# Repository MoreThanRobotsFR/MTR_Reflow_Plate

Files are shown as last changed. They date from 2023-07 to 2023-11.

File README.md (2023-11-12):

# MTR Reflow Plate

<p align="center">

&nbsp;

&nbsp;

&nbsp;

</p>

## Description du projet
Le projet MTR Reflow Plate est un contrôleur de température pour une plaque de refusion. Il permet de réguler la température de la plaque et de suivre les différentes zones de température lors du processus de refusion.

<p align="center">
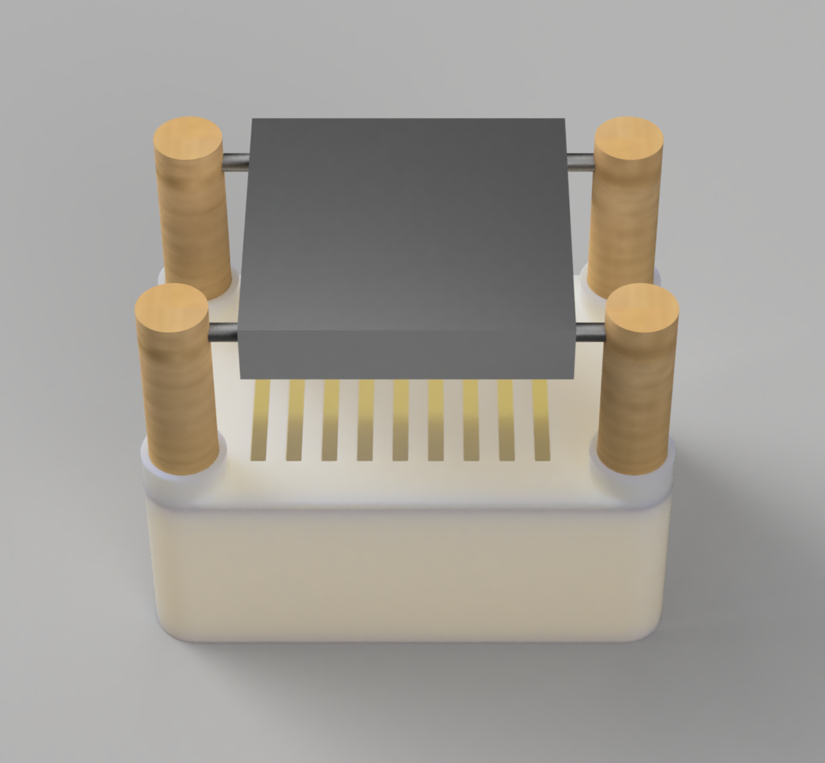
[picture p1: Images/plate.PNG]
MTR Reflow Plate

</p>

## Plateforme matériel
La plateforme matérielle utilisée est l'ESP32 DevKit V1, un microcontrôleur à base de WiFi et Bluetooth intégré. Elle est utilisée en combinaison avec un capteur de température PT100 K avec un MAX31865 et un corps chauffant.

<p align="center">
ESP32, MAX31865 and heating element
</p>

## Installation du firmware
Le code du firmware se trouve dans le répertoire "fireware".

### Prérequis
- La version du logiciel Arduino IDE utilisée doit être compatible avec l'ESP32.
- Les bibliothèques suivantes doivent être installées via le gestionnaire de bibliothèques d'Arduino :
  - Wire
  - SPI
  - SPIFFS
  - [ESPmDNS](https://github.com/espressif/arduino-esp32/tree/master/libraries)
  - [AutoPID](https://github.com/r-downing/AutoPID)
  - [Adafruit_MAX31865](https://github.com/adafruit/Adafruit_MAX31865)
  - [ESPAsyncWebServer](https://github.com/me-no-dev/ESPAsyncWebServer)
  - [AsyncElegantOTA](https://github.com/ayushsharma82/AsyncElegantOTA)
  - [ESPConnect](https://github.com/ayushsharma82/ESPConnect)
  - [ESPAsyncTCP](https://github.com/me-no-dev/ESPAsyncTCP)
  - [Adafruit_BusIO](https://github.com/adafruit/Adafruit_BusIO)
  
  *(`ESPAsyncTCP` et `Adafruit_BusIO` ne sont pas inclus dans le code source du firmware, mais sont nécessaire pour compiler le code. La bibliothèque `ESPmDNS` est incluse dans le package ESP32 pour Arduino IDE)*

### Configuration du matériel
1. Connectez le capteur de température MAX31865 à l'ESP32 comme suit :
   - CS du MAX31865 à la broche `5` 
   - MOSI du MAX31865 à la broche `23` 
   - MISO du MAX31865 à la broche `19` 
   - CLK du MAX31865 à la broche `18` 
2. Connectez le corps chauffant à la broche `4`
3. Connectez le bouton reset à la broche `15` (facultatif)
4. Connectez les leds d'état (facultatif) :
    - LED verte à la broche `12` (dernière etape du processus de refusion)
    - LED rouge à la broche `14` (temperature atteinte)
    - LED bleue à la broche `27` (processus de refusion en cours)
    - LED blanche à la broche `26` (processus de refusion en pause)
    - LED jaune à la broche `32` (mode manuel activé)

### Téléchargement et configuration du firmware
1. Téléchargez le code source du firmware depuis le répertoire "fireware".
2. Ouvrez le fichier "MTR_Reflow_Plate/fireware/src/main.cpp" dans l'IDE Arduino.
3. Modifiez les paramètres de température et de durée des différentes zones selon vos besoins.
4. Compilez et téléchargez le code sur l'ESP32.
4. Si vous souhaitez personnaliser le nom du réseau et le mot de passe WiFi, connectez vous au reseau WiFi "MTR_XXXX" et accédez au portail captif en entrant l'adresse `http://mtr-reflow-plate.local/` dans votre navigateur Web.

### Connexion WiFi avec Portail Captif et Mise à jour OTA

La plaque de refusion MTR utilise la bibliothèque ESPConnect.h pour gérer la connexion WiFi avec portail captif, simplifiant ainsi le processus de configuration du réseau. La bibliothèque AsyncElegantOTA.h permet quant à elle la mise à jour OTA du firmware de la plaque de refusion de manière pratique et sans fil. Ces fonctionnalités offrent une expérience utilisateur améliorée en facilitant la connexion à un réseau WiFi et en permettant la mise à jour du firmware en quelques étapes simples.

## Utilisation de l'interface utilisateur
Lorsque le firmware est correctement chargé sur l'ESP32, vous pouvez accéder à l'interface utilisateur depuis un navigateur Web en entrant l'adresse IP attribuée à l'ESP32.

L'interface utilisateur dispose de plusieurs fonctionnalités :
- **Temperature**: Affiche la valeur actuelle de la température.
- **SET Params**: Permet de définir les paramètres de température et de durée des différentes zones.
- **START**: Démarre le processus de refusion selon les paramètres définis.
- **STOP**: Arrête le processus de refusion.
- **MANU**: Permet de passer en mode de contrôle manuel de la température.
- **Chart**: Affiche un graphique des températures mesurées.

## Exemple de code pour l'utilisation de l'API REST
Il est possible de contrôler la refusion en utilisant l'API REST fournie par l'ESP32.

Voici quelques exemples d'utilisation de l'API REST :
- Récupérer la température actuelle :
  ```
  GET /readTemperature
  ```
- Récupérer la consigne de température actuelle :
  ```
  GET /readSetPoint
  ```
- Définir les paramètres de température et de durée des différentes zones :
  ```
  POST /params
  Content-Type: application/x-www-form-urlencoded
  
  temps_zone_preheating=100000&temperature_zone_preheating=80&temps_zone_recirculation=100000&temperature_zone_recirculation=120&temps_zone_reflow=10000&temperature_zone_reflow=183&temperature_zone_cooling=23
  ```
Pour plus d'informations sur l'utilisation de l'API REST, veuillez consulter le fichier [Firmware/MTR_Reflow_Plate/data/README.md](./Fimrware/MTR_Reflow_Plate/data/README.md).

## Documentation de l'interface web

### Introduction
L'interface web de la plaque de refusion MTR permet de visualiser la température actuelle, de contrôler le mode de fonctionnement (automatique ou manuel) et de configurer les paramètres de refusion. Cette documentation présente les pages principales de l'interface : index.html, manu.html et chart.html.

### index.html
La page index.html est la page d'accueil de l'interface web de la plaque de refusion MTR. Elle permet de visualiser la température actuelle, de configurer les paramètres de refusion et de contrôler le démarrage et l'arrêt du processus de refusion. La page comprend les sections suivantes :

- **Température actuelle** : Affiche la température actuelle de la plaque de refusion en degrés Celsius.
- **Configuration des paramètres** : Permet de définir les temps et les températures de chaque zone de refusion (préchauffage, recirculation, refusion et refroidissement).
- **Boutons de contrôle** : Permettent de démarrer ou d'arrêter le processus de refusion, ainsi que de passer en mode manuel.
- **Affichage des paramètres** : Affiche les paramètres de refusion actuels.

<p align="center">
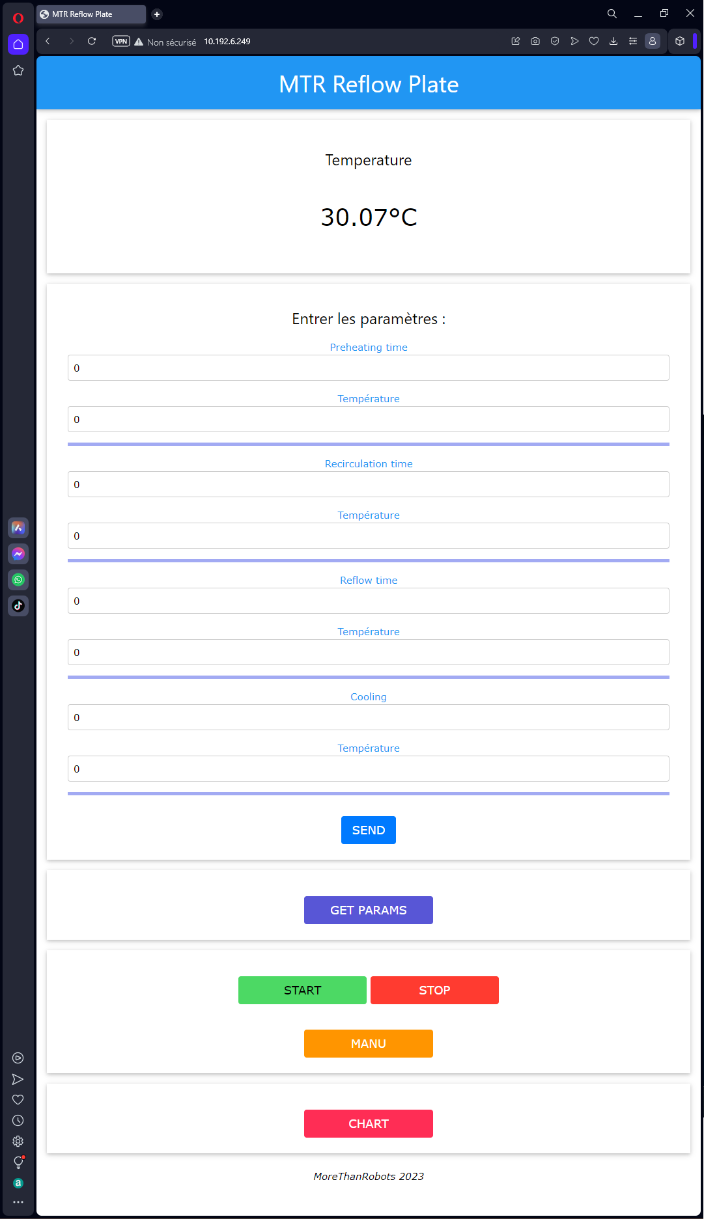
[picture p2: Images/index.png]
index.html

</p>

### manu.html
La page manu.html permet de contrôler la plaque de refusion en mode manuel. Elle affiche la température actuelle et permet de définir une température manuelle. La page comprend les sections suivantes :

- **Température actuelle** : Affiche la température actuelle de la plaque de refusion en degrés Celsius.
- **Définition de la température manuelle** : Permet de définir une température manuelle pour la plaque de refusion.
- **Boutons de contrôle** : Permettent de démarrer ou d'arrêter le chauffage ou le refroidissement de la plaque de refusion.

<p align="center">
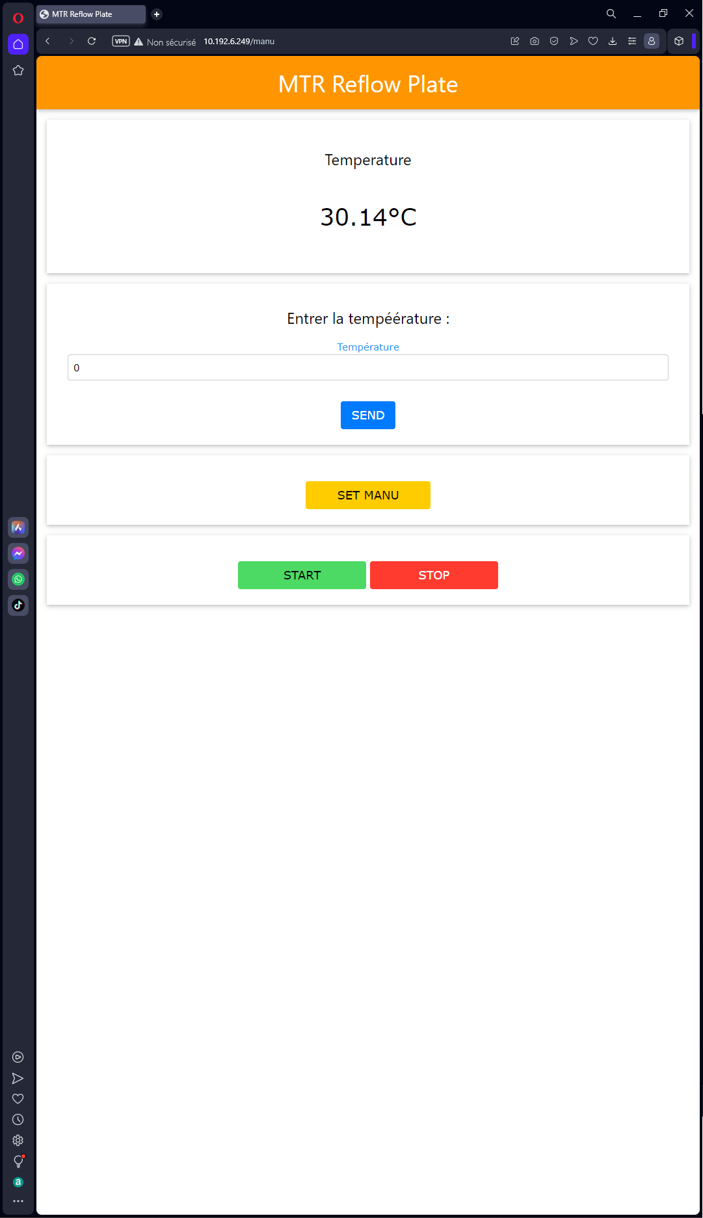
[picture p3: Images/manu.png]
manu.html

</p>

### chart.html
La page chart.html affiche un graphique en temps réel de la température de la plaque de refusion. Le graphique est mis à jour automatiquement toutes les quelques secondes et affiche la température actuelle ainsi que la température de consigne. La page comprend les sections suivantes :

- **Graphique de température** : Affiche le graphique en temps réel de la température de la plaque de refusion et de la température de consigne.

<p align="center">
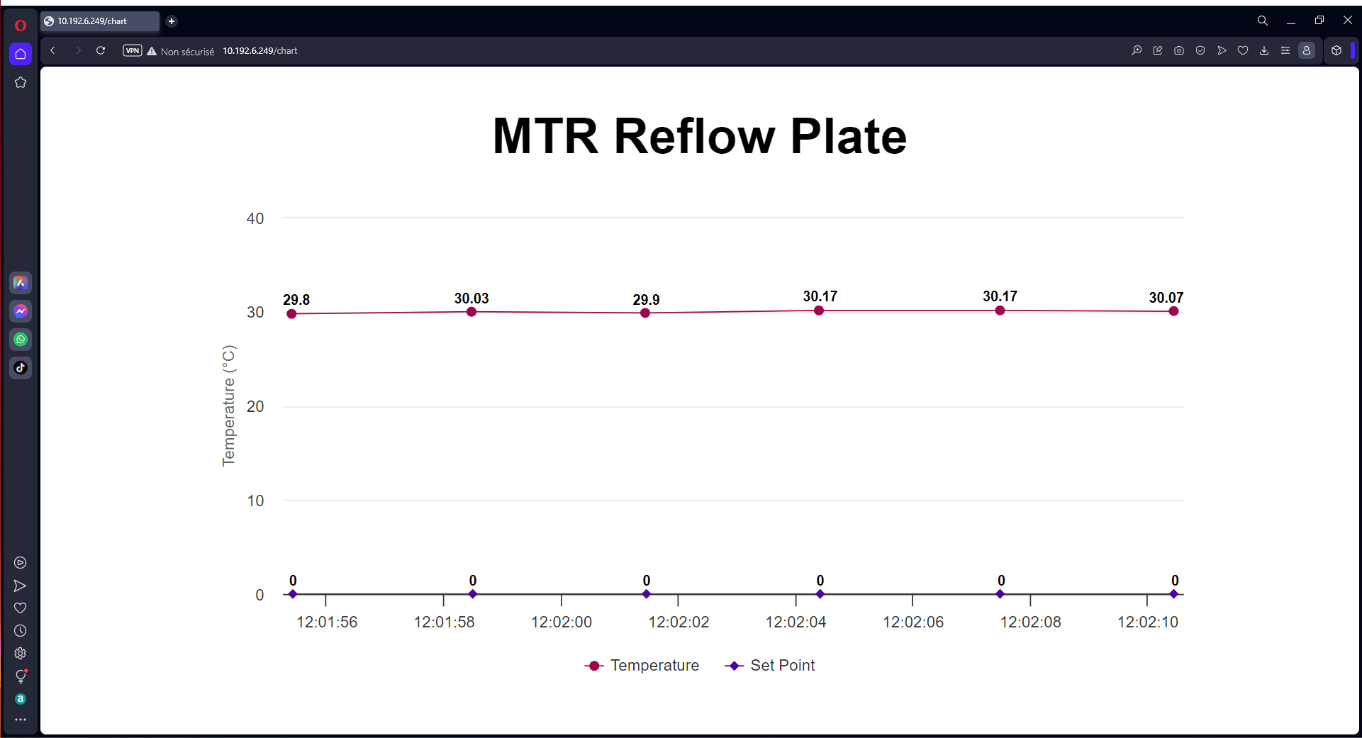
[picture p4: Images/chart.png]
chart.html

</p>

### Conclusion
L'interface web de la plaque de refusion MTR offre une visualisation claire de la température actuelle de la plaque, ainsi que des fonctionnalités de contrôle et de configuration pour le processus de refusion. Les pages index.html, manu.html et chart.html fournissent une interface conviviale pour interagir avec la plaque de refusion et surveiller le processus de refusion en temps réel.

## Auteur
Ce projet a été développé par Ciciliano Altmann pour MTR (MoreThanRobots).

## Licence
Ce projet est distribué sous licence MIT. Veuillez consulter le fichier "LICENSE" pour plus d'informations.

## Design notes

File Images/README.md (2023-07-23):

<p align="center">
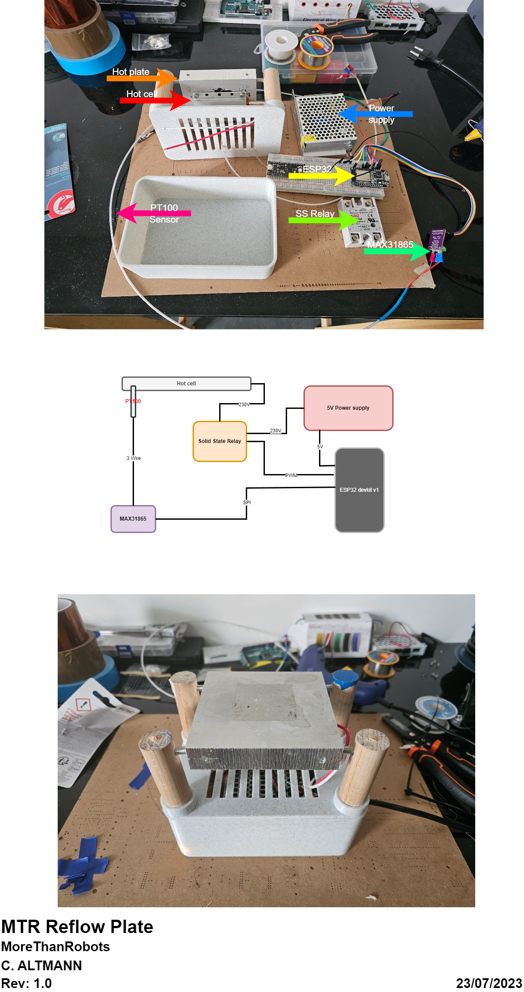
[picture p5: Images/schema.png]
MTR Reflow Plate

</p>

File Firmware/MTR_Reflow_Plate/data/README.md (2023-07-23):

# Documentation de l'API

## Introduction
Cette API vous permet de contrôler la température d'une plaque de refusion. Elle fournit des points de terminaison pour récupérer la température actuelle, définir la température souhaitée, démarrer et arrêter le processus de refusion, et configurer les paramètres de chaque zone de refusion.

## Points de terminaison

### Récupérer la température actuelle
- Méthode : `GET`
- Point de terminaison : `/readTemperature`
- Réponse : La température actuelle en degrés Celsius

### Récupérer la température de consigne
- Méthode : `GET`
- Point de terminaison : `/readSetPoint`
- Réponse : La température de consigne souhaitée en degrés Celsius

### Démarrer le processus de refusion
- Méthode : `GET`
- Point de terminaison : `/start`
- Réponse : Aucune

### Arrêter le processus de refusion
- Méthode : `GET`
- Point de terminaison : `/stop`
- Réponse : Aucune

### Définir le mode manuel
- Méthode : `POST`
- Point de terminaison : `/manu`
- Paramètres de la requête :
  - `manuMode` : le mode souhaité (0 pour automatique, 2 pour manuel)
- Réponse : Aucune

### Définir la température manuelle
- Méthode : `POST`
- Point de terminaison : `/manuSetTemperature`
- Paramètres de la requête :
  - `manuTemperature` : la température souhaitée en degrés Celsius
- Réponse : Aucune

### Définir les paramètres de refusion
- Méthode : `POST`
- Point de terminaison : `/params`
- Paramètres de la requête :
  - `temps_zone_preheating` : la durée de la zone de préchauffage en secondes
  - `temperature_zone_preheating` : la température de la zone de préchauffage en degrés Celsius
  - `temps_zone_recirculation` : la durée de la zone de recirculation en secondes
  - `temperature_zone_recirculation` : la température de la zone de recirculation en degrés Celsius
  - `temps_zone_reflow` : la durée de la zone de refusion en secondes
  - `temperature_zone_reflow` : la température de la zone de refusion en degrés Celsius
  - `temps_zone_cooling` : la durée de la zone de refroidissement en secondes
  - `temperature_zone_cooling` : la température de la zone de refroidissement en degrés Celsius
- Réponse : Aucune

### Récupérer les paramètres de refusion
- Méthode : `GET`
- Point de terminaison : `/getParams`
- Réponse : Les paramètres de refusion actuels sous la forme d'un objet JSON avec les propriétés suivantes :
  - `temps_zone_preheating` : la durée de la zone de préchauffage en secondes
  - `temperature_zone_preheating` : la température de la zone de préchauffage en degrés Celsius
  - `temps_zone_recirculation` : la durée de la zone de recirculation en secondes
  - `temperature_zone_recirculation` : la température de la zone de recirculation en degrés Celsius
  - `temps_zone_reflow` : la durée de la zone de refusion en secondes
  - `temperature_zone_reflow` : la température de la zone de refusion en degrés Celsius
  - `temperature_zone_cooling` : la température de la zone de refroidissement en degrés Celsius

## Explication des modes

### Mode automatique
En mode automatique, le processus de refusion suit un profil de température prédéfini qui comprend quatre zones : préchauffage, recirculation, refusion et refroidissement. La durée et la température de chaque zone peuvent être configurées à l'aide du point de terminaison `/params`.

Pour démarrer le processus de refusion en mode automatique, envoyez une requête GET au point de terminaison `/start`. Le processus de refusion s'exécutera conformément aux paramètres configurés jusqu'à ce qu'il atteigne la zone de refroidissement. À la fin de la zone de refroidissement, le processus s'arrêtera automatiquement.

Pour arrêter le processus de refusion, envoyez une requête GET au point de terminaison `/stop`.

### Mode manuel
En mode manuel, vous pouvez définir une température souhaitée pour la plaque de refusion. La plaque de refusion chauffera ou refroidira jusqu'à atteindre la température souhaitée.

Pour activer le mode manuel, envoyez une requête POST au point de terminaison `/manu` avec le paramètre `manuMode` défini sur 2. Cela activera le mode manuel.

Pour définir la température souhaitée en mode manuel, envoyez une requête POST au point de terminaison `/manuSetTemperature` avec le paramètre `manuTemperature` défini sur la température souhaitée en degrés Celsius.

Pour commencer à chauffer ou à refroidir la plaque de refusion en mode manuel, envoyez une requête GET au point de terminaison `/manuStart`.

Pour arrêter le processus de chauffage ou de refroidissement en mode manuel, envoyez une requête GET au point de terminaison `/manuStop`.

## Gestion des erreurs
En cas d'erreur, le serveur répondra avec un code d'état HTTP approprié et un message d'erreur dans le corps de la réponse.

Codes d'erreur possibles :
- 400 : Requête incorrecte - La requête est invalide ou des paramètres obligatoires sont manquants.
- 404 : Non trouvé - La ressource ou le point de terminaison demandé n'existe pas.
- 500 : Erreur interne du serveur - Une erreur inattendue s'est produite sur le serveur.

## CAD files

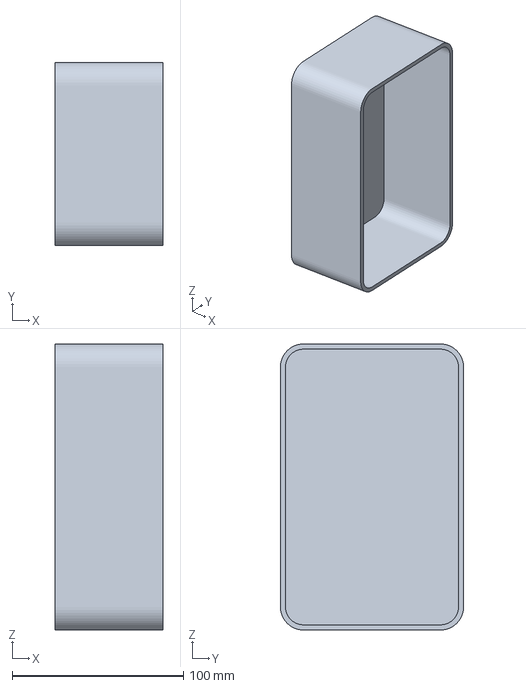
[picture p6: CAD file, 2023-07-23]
Models/support inf v3.3mf
63.0 x 107.0 x 167.0 mm

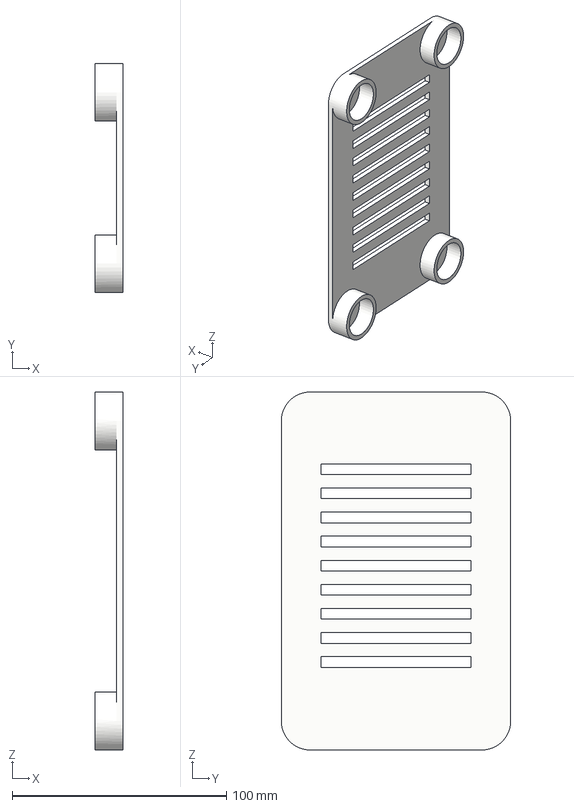
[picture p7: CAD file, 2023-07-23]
Models/support dip v5.3mf
13.0 x 107.0 x 167.0 mm

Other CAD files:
Models/Ass v5.f3z
Models/Cellule chauffante v3.f3d
Models/Pilier v1.f3d
Models/Plateau chauffant v5.f3d
Models/Support disipateur v1.f3d
Models/support dip v5.f3d
Models/support inf v3.f3d

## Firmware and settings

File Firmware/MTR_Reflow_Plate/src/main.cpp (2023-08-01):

/*
Name: MTR Reflow Plate
Version: 1.2.0
Description: This program is used to control the temperature of a reflow plate.
Plateform: ESP32 DevKit V1
Author: Ciciliano Altmann (MTR)
Date: 23/07/2023
License: MIT License
*/

#include <Arduino.h>
#include <Wire.h>
#include <SPI.h>
#include <ESPmDNS.h>
#include <AutoPID.h>
#include <Adafruit_MAX31865.h>
#include <ESPAsyncWebServer.h>
#include <SPIFFS.h>
#include <AsyncElegantOTA.h>
#include <ESPConnect.h>


#define RREF 430.0
#define RNOMINAL 100.0

#define OUTPUT_PIN 4
#define LED_PIN 2
#define LED_GREEN 12
#define LED_RED 14
#define LED_BLUE 27
#define LED_WHITE 26
#define LED_YELLOW 32

#define BUTTON_EREASE 15

#define SPI_CS 5
#define SPI_MOSI 23
#define SPI_MISO 19
#define SPI_CLK 18

#define OUTPUT_MIN 0
#define OUTPUT_MAX 255
#define KP 100
#define KI 0.5
#define KD 0

bool inZone(unsigned long elapsedMilliseconds, unsigned long zoneDuration);
float getTemperature(float R_NOMINAL, float R_REF);
void setTemperature(float temperature);

double temperature, outputVal, setPoint, manuSetPoint;
int startStopManu = 0;
bool manu = false;

// un entier aléatoire en 1000 et 9999

int randNb = random(1001, 9999);
String wifiAPName = "MTR_" + String(randNb);

// Sn42Bi58 paste profile
unsigned long preheatingTime = 60000;     // Durée de la zone 1 (en millisecondes)
unsigned long recirculationTime = 100000; // Durée de la zone 2 (en millisecondes)
unsigned long reflowTime = 90000;         // Durée de la zone 3 (en millisecondes)
unsigned long elapsedMilliseconds, startMillis;

float preheatingTemperature = 90;     // Température de la zone 1 (en degrés Celsius)
float recirculationTemperature = 120; // Température de la zone 2 (en degrés Celsius)
float reflowTemperature = 150;        // Température de la zone 3 (en degrés Celsius)
float coolingTemperature = 23;        // Température de la zone 4 (en degrés Celsius)

AutoPID myPID(&temperature, &setPoint, &outputVal, OUTPUT_MIN, OUTPUT_MAX, KP, KI, KD);
Adafruit_MAX31865 thermo = Adafruit_MAX31865(SPI_CS, SPI_MOSI, SPI_MISO, SPI_CLK);
AsyncWebServer server(80);

void setup()
{
  Serial.begin(115200);

  pinMode(OUTPUT_PIN, OUTPUT);
  pinMode(LED_PIN, OUTPUT);
  pinMode(LED_GREEN, OUTPUT);
  pinMode(LED_RED, OUTPUT);
  pinMode(LED_BLUE, OUTPUT);
  pinMode(LED_WHITE, OUTPUT);
  pinMode(LED_YELLOW, OUTPUT);
  pinMode(BUTTON_EREASE, INPUT_PULLUP);

  thermo.begin(MAX31865_3WIRE); // set to 2WIRE or 4WIRE as necessary

  myPID.setBangBang(10);
  myPID.setTimeStep(50);

  if (!SPIFFS.begin())
  {
    Serial.println("Erreur SPIFFS...");
    return;
  }

  File root = SPIFFS.open("/");
  File file = root.openNextFile();

  while (file)
  {
    Serial.print("File: ");
    Serial.println(file.name());
    file.close();
    file = root.openNextFile();
  }

  ESPConnect.autoConnect(wifiAPName.c_str());

  Serial.print("AP Name: ");
  Serial.println(wifiAPName);

  if (ESPConnect.begin(&server))
  {
    Serial.println("Connected to WiFi");
    Serial.println("IPAddress: " + WiFi.localIP().toString());
  }
  else
  {
    Serial.println("Failed to connect to WiFi");
  }

  MDNS.begin("mtr-reflow-plate");
  MDNS.addService("http", "tcp", 80);
  MDNS.addServiceTxt("http", "tcp", "name", "MTR Reflow Plate");
  MDNS.addServiceTxt("http", "tcp", "version", "1.2.0");

  server.on("/", HTTP_GET, [](AsyncWebServerRequest *request)
            { request->send(SPIFFS, "/index.html", "text/html"); });

  server.on("/chart", HTTP_GET, [](AsyncWebServerRequest *request)
            { request->send(SPIFFS, "/chart.html", "text/html"); });

  server.on("/manu", HTTP_GET, [](AsyncWebServerRequest *request)
            { request->send(SPIFFS, "/manu.html", "text/html"); });

  server.on("/script.js", HTTP_GET, [](AsyncWebServerRequest *request)
            { request->send(SPIFFS, "/script.js", "text/javascript"); });
  
  server.on("/export-data.js", HTTP_GET, [](AsyncWebServerRequest *request)
            { request->send(SPIFFS, "/export-data.js", "text/javascript"); });
  
  server.on("/exporting.js", HTTP_GET, [](AsyncWebServerRequest *request)
            { request->send(SPIFFS, "/exporting.js", "text/javascript"); });
  
  server.on("/highcharts.js", HTTP_GET, [](AsyncWebServerRequest *request)
            { request->send(SPIFFS, "/highcharts.js", "text/javascript"); });
  
  server.on("/jquery-3.5.1.min.js", HTTP_GET, [](AsyncWebServerRequest *request)
            { request->send(SPIFFS, "/jquery-3.5.1.min.js", "text/javascript"); });
  
  server.on("/offline-exporting.js", HTTP_GET, [](AsyncWebServerRequest *request)
            { request->send(SPIFFS, "/offline-exporting.js", "text/javascript"); });
  
  server.on("/w3-colors-ios.css", HTTP_GET, [](AsyncWebServerRequest *request)
            { request->send(SPIFFS, "/w3-colors-ios.css", "text/css"); });
  
  server.on("/w3.css", HTTP_GET, [](AsyncWebServerRequest *request)
            { request->send(SPIFFS, "/w3.css", "text/css"); });

  server.on("/readTemperature", HTTP_GET, [](AsyncWebServerRequest *request)
            { request->send(200, "text/plain", String(temperature)); });

  server.on("/readSetPoint", HTTP_GET, [](AsyncWebServerRequest *request)
            { request->send(200, "text/plain", String(setPoint)); });

  server.on("/start", HTTP_GET, [](AsyncWebServerRequest *request)
            {
    startStopManu = 1;
    request->send(204); });

  server.on("/stop", HTTP_GET, [](AsyncWebServerRequest *request)
            {
    startStopManu = 0;
    request->send(204); });

  server.on("/manu", HTTP_POST, [](AsyncWebServerRequest *request)
            {

  if(request->hasParam("manuMode", true)){
      String message;
      message = request->getParam("manuMode", true)->value();
      startStopManu = message.toInt();
    }
    request->send(204); });

  server.on("/manuStart", HTTP_GET, [](AsyncWebServerRequest *request)
            {
  manu = true;
  request->send(204); });

  server.on("/manuStop", HTTP_GET, [](AsyncWebServerRequest *request)
            {
  manu = false;
  request->send(204); });

  server.on("/params", HTTP_POST, [](AsyncWebServerRequest *request)
            {

  if(request->hasParam("temps_zone_preheating", true)){
      String message;
      message = request->getParam("temps_zone_preheating", true)->value();
      preheatingTime = message.toInt();
  }

  if(request->hasParam("temperature_zone_preheating", true)){
      String message;
      message = request->getParam("temperature_zone_preheating", true)->value();
      preheatingTemperature = message.toInt();
  }

  if(request->hasParam("temps_zone_recirculation", true)){
      String message;
      message = request->getParam("temps_zone_recirculation", true)->value();
      recirculationTime = message.toInt();
  }

  if(request->hasParam("temperature_zone_recirculation", true)){
      String message;
      message = request->getParam("temperature_zone_recirculation", true)->value();
      recirculationTemperature = message.toInt();
  }

  if(request->hasParam("temps_zone_reflow", true)){
      String message;
      message = request->getParam("temps_zone_reflow", true)->value();
      reflowTime = message.toInt();
  }

  if(request->hasParam("temperature_zone_reflow", true)){
      String message;
      message = request->getParam("temperature_zone_reflow", true)->value();
      reflowTemperature = message.toInt();
  }

  if(request->hasParam("temperature_zone_cooling", true)){
      String message;
      message = request->getParam("temperature_zone_cooling", true)->value();
      coolingTemperature = message.toInt();
  }

  request->send(204); });

  server.on("/manuSetTemperature", HTTP_POST, [](AsyncWebServerRequest *request)
            {

  if(request->hasParam("manuTemperature", true)){
      String message;
      message = request->getParam("manuTemperature", true)->value();
      manuSetPoint = message.toInt();
  }

  request->send(204); });

  server.on("/getParams", HTTP_GET, [](AsyncWebServerRequest *request)
            {
  String json = "{";
  json += "\"temps_zone_preheating\":"; 
  json += String(preheatingTime);
  json += ",";

  json += "\"temperature_zone_preheating\":";
  json += String(preheatingTemperature);
  json += ",";

  json += "\"temps_zone_recirculation\":";
  json += String(recirculationTime);
  json += ",";

  json += "\"temperature_zone_recirculation\":";
  json += String(recirculationTemperature);
  json += ",";

  json += "\"temps_zone_reflow\":";
  json += String(reflowTime);
  json += ",";

  json += "\"temperature_zone_reflow\":";
  json += String(reflowTemperature);
  json += ",";

  json += "\"temperature_zone_cooling\":";
  json += String(coolingTemperature);

  json += "}";

  request->send(200, "text/plain", json); });

  AsyncElegantOTA.begin(&server); // Start ElegantOTA
  
  server.begin();
  Serial.println("Serveur actif!");
}

void loop()
{
  temperature = getTemperature(RNOMINAL, RREF);

  if (startStopManu == 0)
    digitalWrite(LED_WHITE, 1);
  else
    digitalWrite(LED_WHITE, 0);

  if (startStopManu == 2)
    digitalWrite(LED_YELLOW, 1);
  else
    digitalWrite(LED_YELLOW, 0);

  if (startStopManu == 1 || manu == true)
    digitalWrite(LED_BLUE, 1);
  else
    digitalWrite(LED_BLUE, 0);

  if (startStopManu == 1)
  {

    elapsedMilliseconds = millis() - startMillis;

    myPID.run();
    analogWrite(OUTPUT_PIN, outputVal);
    digitalWrite(LED_RED, myPID.atSetPoint(3));

    // Zone 1: Preheating
    if (inZone(elapsedMilliseconds, preheatingTime))
    {
      setTemperature(preheatingTemperature);
    }
    // Zone 2: Recirculation
    else if (inZone(elapsedMilliseconds - preheatingTime, recirculationTime))
    {
      setTemperature(recirculationTemperature);
    }
    // Zone 3: Reflow
    else if (inZone(elapsedMilliseconds - preheatingTime - recirculationTime, reflowTime))
    {
      setTemperature(reflowTemperature);
      digitalWrite(LED_GREEN, 1);
    }
    // Zone 4: Cooling
    else
    {
      setTemperature(coolingTemperature);
      digitalWrite(LED_GREEN, 0);
      startStopManu = 0;
    }
  }
  else if (startStopManu == 2)
  {
    startMillis = millis();
    setPoint = manuSetPoint;

    if (manu)
    {
      myPID.run();
      analogWrite(OUTPUT_PIN, outputVal);
      digitalWrite(LED_RED, myPID.atSetPoint(3));
    }
    else
    {
      analogWrite(OUTPUT_PIN, 0);
    }
  }
  else if (startStopManu == 0)
  {
    analogWrite(OUTPUT_PIN, 0);
    setPoint = 0;
    startMillis = millis();
  }

  if (digitalRead(BUTTON_EREASE) == LOW)
  {
    delay(3000);
    if (digitalRead(BUTTON_EREASE) == LOW)
    {
      ESPConnect.erase();
      ESP.restart();
    }
  }
}

float getTemperature(float R_NOMINAL, float R_REF)
{
  float temp = thermo.temperature(R_NOMINAL, R_REF);
  return temp;
}

bool inZone(unsigned long elapsedMilliseconds, unsigned long zoneDuration)
{
  return (elapsedMilliseconds < zoneDuration);
}

// Set the temperature of the heating plate
void setTemperature(float temperature)
{
  setPoint = temperature;
}

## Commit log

2023-07-23 Documentation de l'API
2023-07-23 Documentation de l'API détaillée
2023-07-23 add 3d file
    [Ass v5.f3z, Cellule chauffante v3.f3d, Pilier v1.f3d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]
2023-07-27 add reset button for captive portal
